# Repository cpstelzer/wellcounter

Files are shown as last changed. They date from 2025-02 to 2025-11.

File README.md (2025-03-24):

# Wellcounter: Automated High-Throughput Phenotyping for Aquatic Microinvertebrates

## Overview
The **Wellcounter** is an open-source platform designed for **automated high-throughput phenotyping** of aquatic microinvertebrates. It enables large-scale ecological experiments by automating **image acquisition, processing, and analysis**, significantly reducing manual effort in tracking population growth and swimming behavior.


**Fig. 1 Wellcounter device**


**Fig. 2 Left: 6-well plate, Middle: Rotifers detected in one well, Right: Detected individuals**

This repository provides resources for **building and using** the Wellcounter, including:
- **Hardware design**: Instructions for assembling the Wellcounter using commercially available and 3D-printed components.
- **Software**: Python-based modules for automated data acquisition, image analysis, and motion tracking.
- **Documentation**: A detailed manual and supplementary materials supporting setup and optimization.

The Wellcounter was introduced in:
> Stelzer, C.-P., & Groffman, D. (2025). Wellcounter: Automated high-throughput phenotyping for aquatic microinvertebrates. Methods in Ecology and Evolution, 00, 1–14. https://doi.org/10.1111/2041-210X.70012

## Features
- **Automated Imaging**: Captures high-resolution images and videos using a motorized **XY linear guide system**.
- **High-Throughput Analysis**: Handles up to **42 six-well plates** (252 populations) per batch. The recording of one batch takes about 1-1.5 hours per day. Multiple batches are possible
- **Image & Motion Analysis**: Quantifies population size and swimming behavior.
- **Customizable & Open-Source**: Fully programmable and adaptable to different microorganisms.
- **3D-Printed Components**: CAD files for custom-designed adapters and mounts included.

## Getting Started
### 1. Hardware Setup
The Wellcounter integrates a **Basler a2A4504-27g5m digital camera**, a **telecentric lens**, and a **darkfield illumination ring**. Detailed **assembly instructions** are available in the **Wellcounter Manual**.

### 2. Software Installation
The Wellcounter software is written in Python and requires installation via **Conda**.
```bash
conda env create -f wellcount6_pi.yml
conda activate wellcount6_pi
```

### 3. Data Acquisition & Analysis
- **Automated Imaging**: The `wc_record_experiment.py` script controls the Wellcounter for video acquisition.
- **Image Analysis**: The `wc_analyze_one_sample.py` script detects and quantifies microorganisms in a recorded movie.
- **Motion Analysis**: The motion module tracks swimming behavior over time.
- **Optimization Module**: Fine-tunes imaging parameters using a training dataset.

## Documentation & Tutorials
- **[Wellcounter Manual](https://github.com/cpstelzer/wellcounter)**: Step-by-step guide to assembling and using the system.
- **Example Datasets**:
  Training & test data available via Zenodo:
  - 10.5281/zenodo.14833208
  - 10.5281/zenodo.14833370
  - 10.5281/zenodo.14833381

## Citation
If you use the Wellcounter in your research, please cite:
> Stelzer, C.-P., & Groffman, D. (2025). Wellcounter: Automated high-throughput phenotyping for aquatic microinvertebrates. Methods in Ecology and Evolution, 00, 1–14. https://doi.org/10.1111/2041-210X.70012

## License
This project is released under an **open-source license**, allowing modifications and contributions from the scientific community.

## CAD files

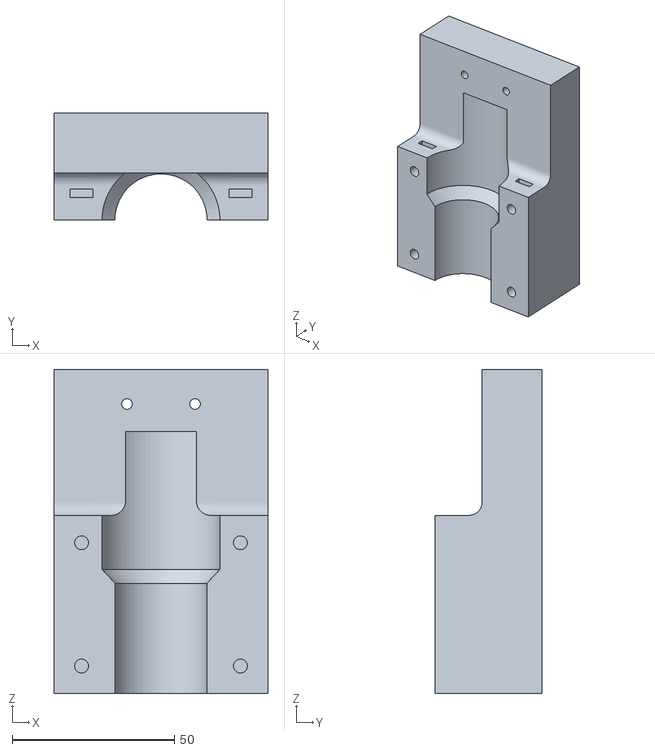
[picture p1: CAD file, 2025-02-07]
3D_print/OPT10M03_adapter_pt2.stl
66.0 x 33.0 x 100.0

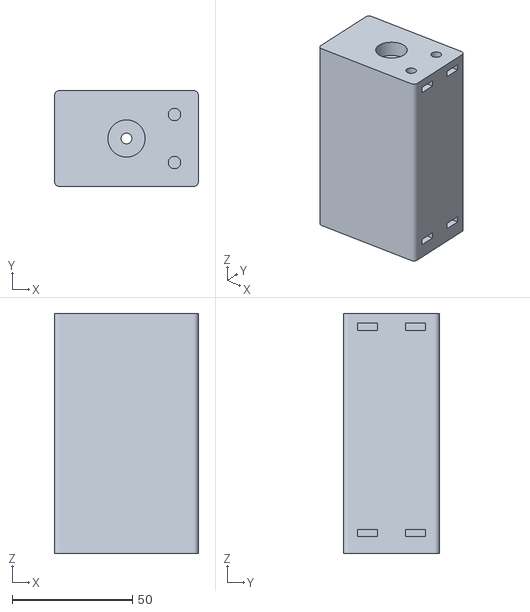
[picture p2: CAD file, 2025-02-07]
3D_print/drag_chain_spacer.stl
60.0 x 40.0 x 100.0

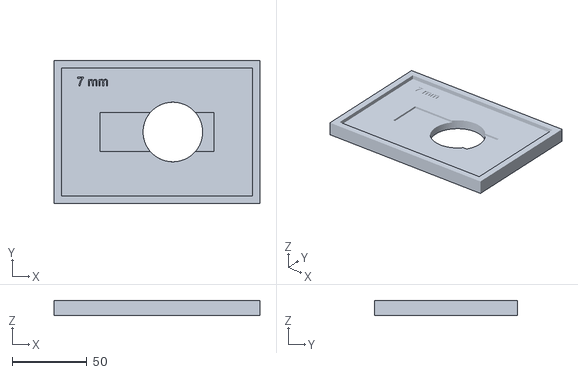
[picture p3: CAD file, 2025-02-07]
3D_print/USAF_1951_slide_holder_7mm.stl
138.3 x 96.0 x 10.0

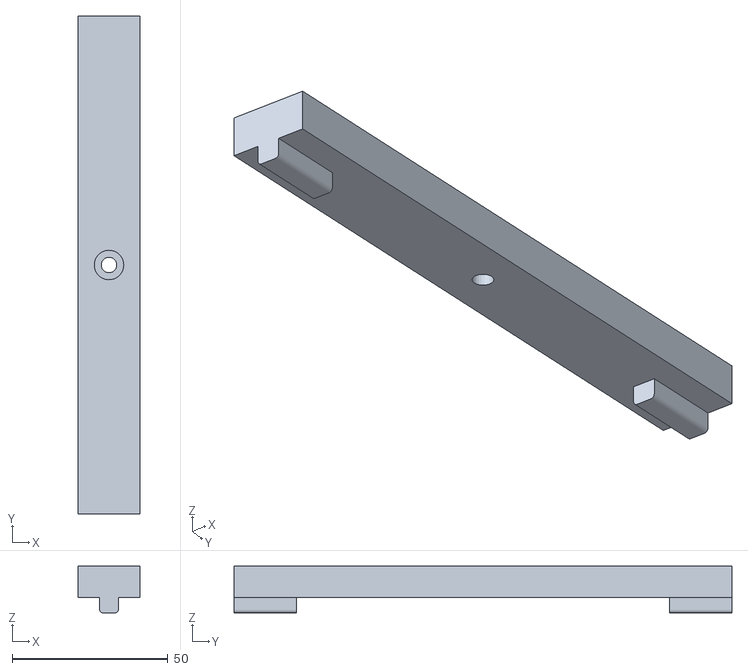
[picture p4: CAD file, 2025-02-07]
3D_print/alignment_rail_long.stl
20.0 x 160.0 x 15.0

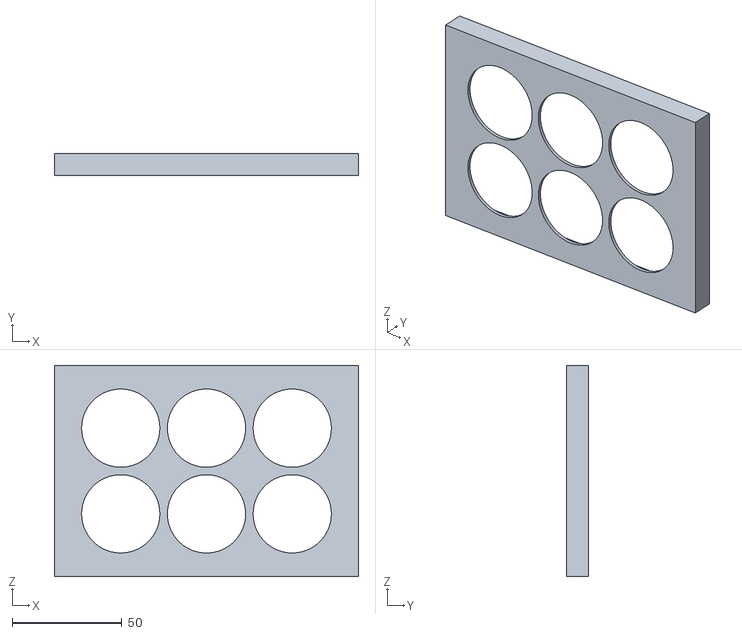
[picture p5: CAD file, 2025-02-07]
3D_print/holder_6wellplate.stl
138.3 x 10.0 x 96.0

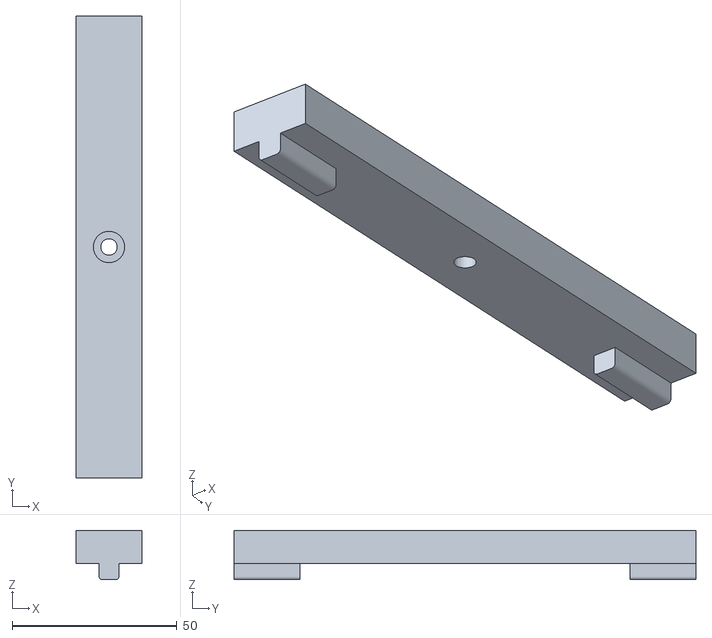
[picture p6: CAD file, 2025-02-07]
3D_print/alignment_rail_short.stl
20.0 x 140.0 x 15.0

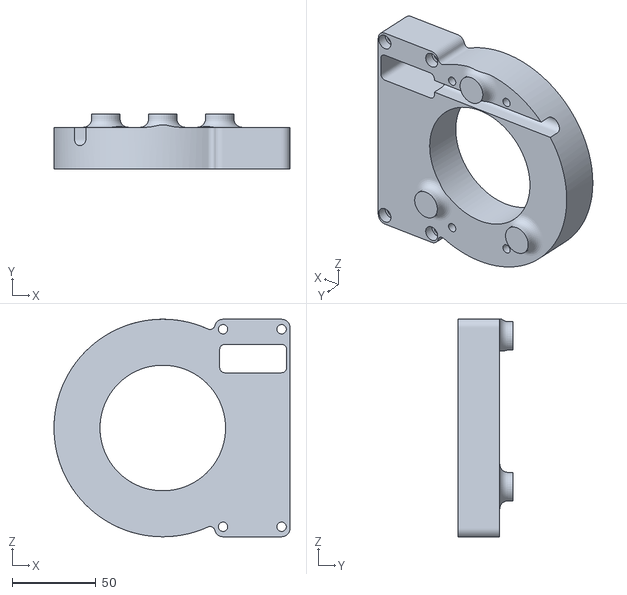
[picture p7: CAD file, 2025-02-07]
3D_print/adapter_ringlight.stl
141.0 x 33.0 x 130.0

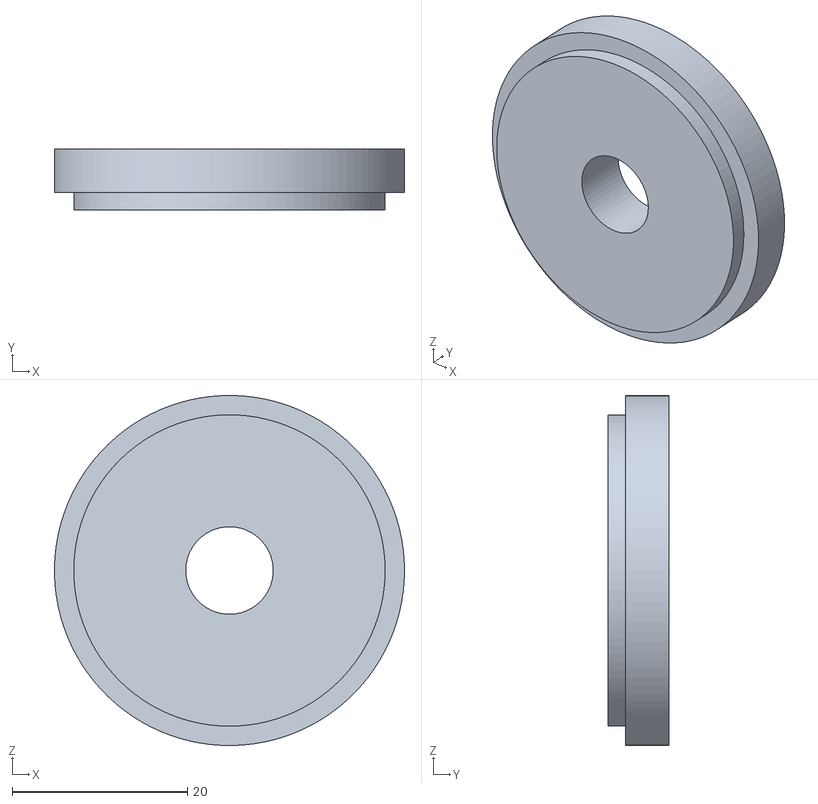
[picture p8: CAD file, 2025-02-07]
3D_print/center_disc_6well_1cm_opening.stl
40.0 x 7.00 x 40.0

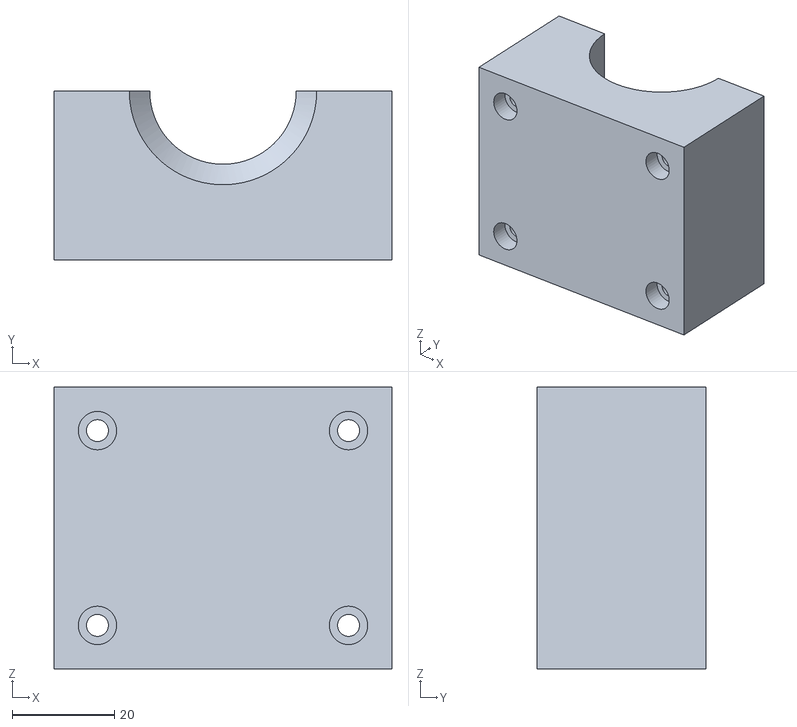
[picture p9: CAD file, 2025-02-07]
3D_print/OPT10M03_adapter_pt1.stl
66.0 x 33.0 x 55.0

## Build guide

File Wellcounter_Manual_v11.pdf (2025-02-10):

# Wellcounter Manual v1.1

### Claus-Peter Stelzer

Research Institute for Limnology, Mondsee, Universität Innsbruck Email: claus-peter.stelzer@uibk.ac.at

This manual is a part of the publication:

Stelzer, C.P. & Groffman, D. (2025) "Wellcounter: Automated High-Throughput Phenotyping for Aquatic Microinvertebrates". Methods in Ecology and Evolution

Future versions of this manual will be available at: https://github.com/cpstelzer/wellcounter

## Table of Contents

## Introduction

The Wellcounter is an advanced platform for automated high-throughput phenotyping of aquatic microinvertebrates (100–2000 µm) using common multiwell plates. It facilitates large-scale ecological experiments by automating image acquisition, processing, and analysis.

The system consists of:

- Hardware: A high-resolution camera, telecentric lens, motorized linear guides, and darkfield illumination.
- Software: Python-based modules for automated data collection and analysis.

This manual provides step-by-step instructions for building the hardware, setting up the software, and using the Wellcounter effectively.

## Building instructions

The Wellcounter device (Fig. 1) integrates an open-source linear guide system, custom 3D-printed parts, and high-quality optical components for capturing well-resolved images of samples. This manual provides detailed instructions on constructing your own Wellcounter device, covering the essential components and assembly steps. By following these guidelines, you should be able to replicate our prototype, or build a device with similar characteristics.

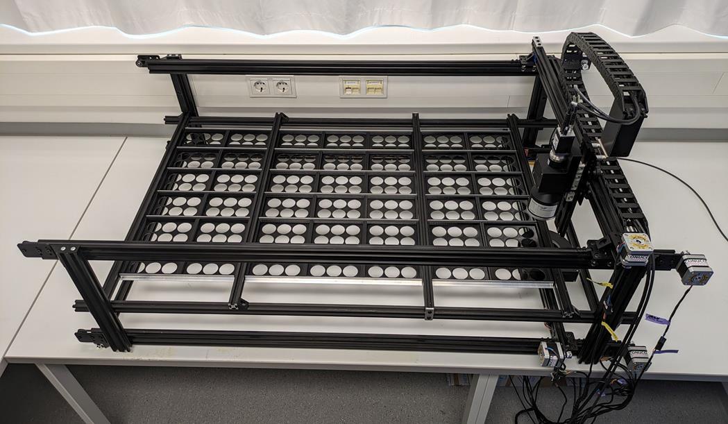
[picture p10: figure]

Fig. 1. The Wellcounter device.

### Linear guide system

We recommend purchasing a pre-assembled linear guide system to save time and avoid potential mechanical issues from DIY construction. The design we use is based on OpenBuilds (https://us.openbuilds.com), an open-source platform that provides affordable and modular components, including aluminum extrusions, belt drives, and stepper motors. You can buy the components or pre-assembled XY linear guides from OpenBuilds (builds.openbuilds.com), or from a reseller (e.g., conucon.de). Usually, such linear guides come at default dimensions, e.g., 1000 x1000 mm, and consist of a frame with two axes travelling in the X- and Y- direction.

In our Wellcounter design, we customized several aspects:

- We use two XY linear guides that are assembled on top of each other. The linear guide at the upper level holds the camera/lens while one at the bottom level holds the ring illumination (Fig. 2).
- The object plane, which holds the six-well plates, is located in between the two linear guides. It is a fixed rectangular frame consisting of 20x20 mm aluminum extrusions and T-profiles (Fig. 2 B-E).
- All three levels are screwed together by four vertical braces consisting of 20x40 mm extrusions. The distance between the top plane and the object plane in our device is 140
mm (Fig. 2 A, E).
- Our linear guides have custom dimensions of 750 x 1150 mm, to better fit on the table in our lab

Checklist for ordering a linear guide system:

- Pre-assembled XY linear guide system
- Stepper motors (NEMA 17 or NEMA 23), motor drivers, and cables
- 12V, 5A power supply
- Microcontroller (e.g., OpenBuilds BlackBox, or Arduino with GRBL firmware)

Apart from these components, you will also need a PC, which is connected via USB to the microcontroller. This PC controls the linear guide either through a low-level table control software provided from the manufacturer (e.g., OpenBuilds CONTROL or CONUCON software), or programmatically via Python commands (e.g., in the Wellcounter acquisition module). For more details, see the next section (Basic software control).

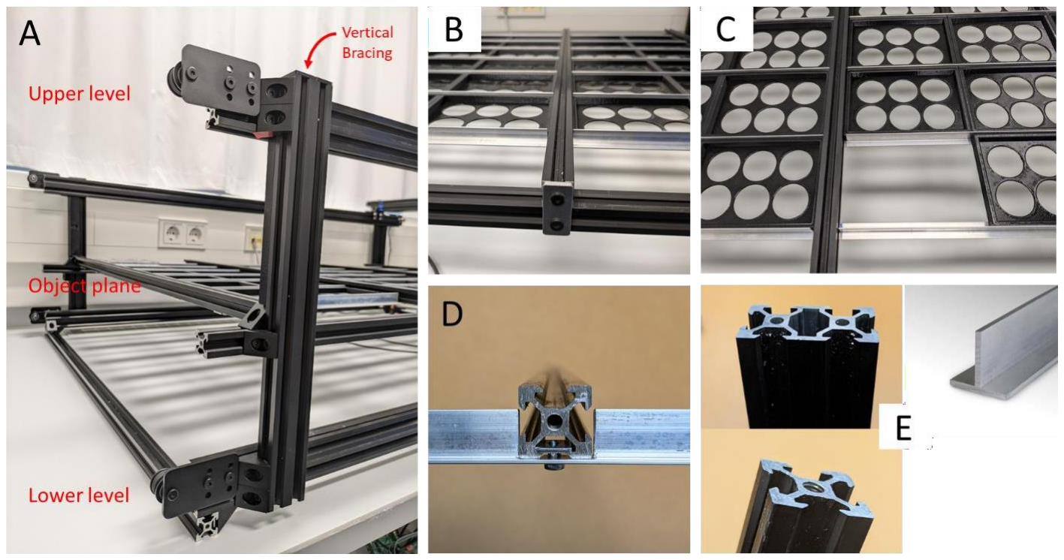
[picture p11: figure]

Fig. 2. Components of the Wellcounter device. A The three levels (Upper level, object plane, lower level) of the Wellcounter device are held together by four vertical braces consisting of 20x40mm aluminum extrusions. B, C The object plane consists of 20x20mm extrusions and aluminum T-profiles, which hold the black 3D-printed wellplate holders. D Connection between T-profiles and 20x20 extrusion. E Raw components of the object plane: 20x40 mm and, 20x20mm extrusions, T-profile.

### Optical components and illumination

The most important aspect of choosing a camera and lens is ensuring that their optical characteristics (e.g., field of view, working distance) align with the spatial constraints of the objects to be imaged, such as the size of a well or the available distance between the camera/lens and the object plane. Ideally, the optical system should be configured so that one well is displayed in a format that fills the camera's sensor. Online calculators (e.g., baslerweb.com/en/tools/lens-selector/) can assist with selecting suitable optical components.

Our Wellcounter prototype utilizes a monochrome digital camera (Basler a2A4504-27g5m) with a Sony IMX541 CMOS sensor, capable of delivering up to 27 frames per second at a resolution of 20.2 MP (4512 x 4512 pixels). We use a telecentric lens (model: OPT-10M035-110) with 0.35X magnification and a working distance of 110 mm. This optical configuration produces a field of view with a 46.3 mm diameter, precisely covering one well of a 6-well plate (Greiner Bio One, Model: 657160). The camera is connected to a PC through a 5-GigE interface card. Darkfield background illumination is provided by an MBJ horizontal ringlight HDF-07-BE-s (MBJ imaging, Hamburg, Germany) with a peak wavelength of 465 nm (blue light).

To aid in selecting components for similar applications, we offer the following recommendations:

- Use an industrial-grade camera that can be controlled via Python commands (e.g., through Basler Pylon). Consumer digital cameras are generally unsuitable, as they lack low-level control capabilities and store images/movies on the camera itself rather than on a computer, where the analysis is performed.
- If color is not essential to your application, opt for a monochrome camera because it provides higher sensitivity and greater resolution by capturing more light at each pixel compared to a color sensor. Monochrome cameras avoid the color filter array used in color sensors, allowing for sharper imaging, especially beneficial in low-light conditions or when using specific wavelengths for illumination.
- Invest in a telecentric lens. Although telecentric lenses are considerably more expensive than standard lenses, they produce an essentially distortion-free image, ensuring accurate representation of each object's position and size.
- Ensure that no downstream component limits the camera's frame rate. Use a suitable high-bandwidth interface card for the computer if needed. For example, we added a 5-GigE interface card to our setup.
- Monochrome illumination, ideally atshort wavelengths, offers superior sharpness. We use blue light illumination at 465 nm, but other wavelengths can also be effective.

### 3D-printed components

In the Wellcounter, we use 3D-printed adapters to mount the camera/lens and ring light onto the linear guides, or as holders for 6-well plates onto the object plane (Fig. 3). We used black PETG as printing material, which is cost-efficient, easy to print, and durable.

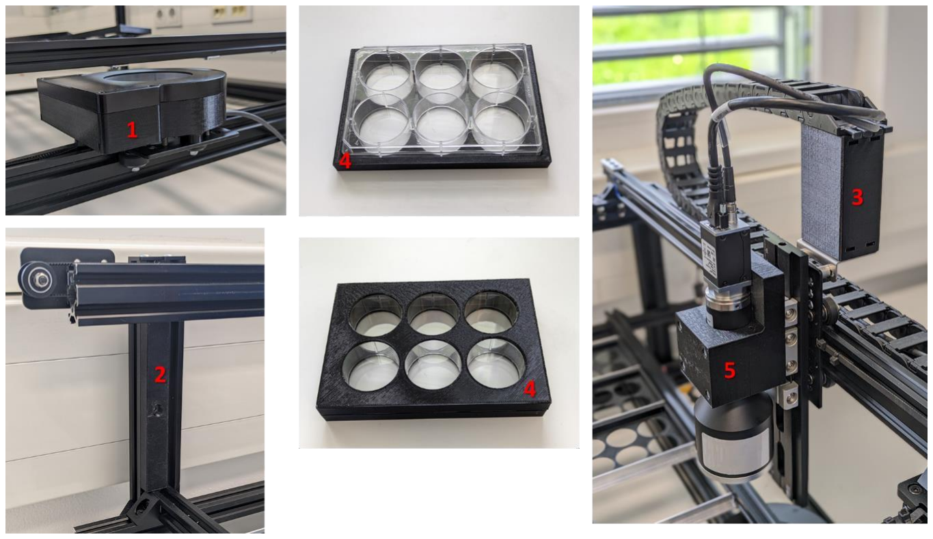
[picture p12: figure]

Fig. 3. 3D-printed parts of the Wellcounter. 1 Mounting adapter for ring illumination, 2 Alignment rail for adjusting the distance between upper level and object plane, 3 Spacer for drag chain, 4 Well plate holder used to mount well plates onto the object plane, or can be placed on top of a well plate to block light signals outside the well, 5 Mounting adapter for camera and lens.

If you do not have access to a 3D-printer, you can upload the provided STL-files to a 3D printing service. However, if you chose this approach, we recommend having a test print done for one of the 6-well plate holders before printing the full set of 84 pieces, since the tolerances of 3D printed parts may vary from printer to printer.

The 3D printed parts are specifically designed for the optical components stated above. They will probably not fit for different models, or if manufacturers chose to change the dimensions of the existing models. In these cases, it would be necessary to design new adapters that match the dimensions of the new optical components.

## Basic software control

The goal of this section is to familiarize you with software control of the Wellcounter device. We will install the Conda environment, which contains all the dependencies for running the Wellcounter software written in Python. We will also generate a csv fie in which the coordinates to the physical positions of all plates and wells on the object plane are stored.

### Background

At the low level, the XY linear guide system of the Wellcounter is controlled by commands written in G-code, which tell the motors how to move. This G-code is sent to the microcontroller, which converts it into electrical signals that ultimately drive the stepper motors translate it into actions like moving along the X and Y axes.

Example of a G-code command:

G1 X5 Y10

This moves the device 5 units in the X-axis and 10 units in the Y-axis. Your linear guide system should come with a software that allows directly entering G-code commands.

G-code commands can also be sent to the microcontroller from within a Python-program using the package pyserial, which is the method how the Wellcounter interfaces with the linear guide. Here is the same command send from within Python:

gcode_command = 'G1 X5 Y10\n'

ser.write(gcode_command.encode('utf-8'))

Note that ‘\n’ (newline) indicates the end of the command.

### Setting up the Conda environment

To run the Wellcounter software on your local computer, you need to first replicate the required environment with all its dependencies. The easiest way to accomplish this is to install the package manager Anaconda on your computer (http://anaconda.org/). After installing Anaconda, complete the following steps:

1) Copy the Wellcounter environment-file to a destination folder on your PC, e.g.:

C:/Users/Anaconda/wellcount6_pi.yml
2) Install the environment on your PC with the following command:

conda env create -f C:/Users/Anaconda/wellcount6_pi.yml
This step only needs to be done once.
3) After the environment has been installed, open the Anaconda terminal and activate the

Wellcounter environment by typing:

conda activate wellcount6_pi
The terminalshould now display “(wellcount6_pi)” followed by your current working directory.
4) Copy all the Wellcounter software files into your working directory. This step only needs to be

done once.

You can verify the correct installation of your Wellcounter Conda-environment by running an analysis of pre-recorded sample movies. To run one of the example scripts, e.g., wc_analyze_one_sample.py, follow these steps:

- Copy the mp4-movie file that is to be analyzed into any directory of your choice.

- Open the example script wc_analyze_one_sample.py in an editor of your choice (e.g.,

Spyder, which is part of the Anaconda package) and adjust the variables ‘data_dir’ and

‘video_file’ to match the location of your video-file. Save these changes.

- To execute the script, go to the Anaconda terminal (‘wellcount6_pi’ activated), navigate

to the directory where your Wellcounter software is stored, and and type:

python wc_analyze_one_sample.py
- Depending on the hardware of your computer, the analysis will take 20-60 seconds (if

only counting is done), or a few minutes (if motion analysis is done as well) and it will

output the main results on the screen (Fig. 4)

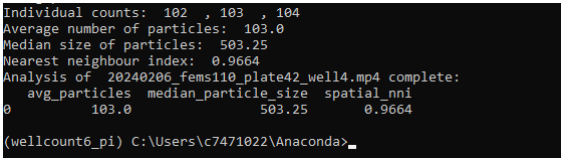
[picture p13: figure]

Fig. 4. Typical screen output after running image analysis.

Furthermore, after the analysis is complete, you will find two new folders in the same directory as

your mp4-file, which contain the results of particle detection and motion analysis, respectively (Fig.

5).

Fig. 5 Folders containing the results of image and motion analysis.

### Generating the wellpositions_all.csv file

During recording of an experiment, the Wellcounter moves the camera/illumination unit to each individual well in the object plane, thus visiting a total of up to 42 x 6 = 252 wells. The G-code commands required for this movement are calculated based on the positions of each of these 252 wells in the object plane. Before the first use of the Wellcounter, the exact positions of these wells have to be empirically determined and stored in a file called wellpositions_all.csv. This procedure needs to be done only once, unless you make changes in the object plane that alter the physical arrangement of the well plates. As a reference point (X0, Y0) of the coordinate system of the object plane, we use the center of “well 6” of “plate 42”, which is located in the low right corner of the object plane (Fig. 7). The workflow for generating the wellpositions_all.csv file is as follows:

- Put a small piece of white cardboard behind the ring illumination, to create a white background (see below, Initial calibration in Workflow1: Data Acquisition). Place all 42 wellplate holders on the object plane.
- Start your low-level table control software provided with the XY linear guide (e.g., CONUCON software) and the camera control software of your camera manufacturer (e.g., Basler Pylon).
- Move the camera and illumination units to “well 6” of “plate 42”. Tare this position to the coordinates 0, 0 (X, Y). This procedure is described in more detail below (see below, Initial calibration in Workflow1: Data Acquisition).
- Now move the camera and illumination to “well 6” of “plate 41”. Note the XY-coordinates of well 6 of plate 41 and continue with each the remaining 40 plate holders.
- Enter all 42 coordinates in a text editor and save the results as a csv-file (wellpositions_w6.csv), which will look like this
plate,well,originX,originY
1,6,86.680,48.448
2,6,86.714,38.704
3,6,86.740,28.986
4,6,86.775,19.256
…
- To calculate the positions of the remaining wells no. 1-5 of each plate, you can use our Python script calculate_all_wellpositions.py. This script outputs the file wellpositions_all.csv which contains the coordinates of all 42x6=252 wells:
plate,well,X,Y
1,1,94.48,52.35
1,2,90.58,52.35
1,3,86.68,52.35
1,4,94.48,48.45
1,5,90.58,48.45
1,6,86.68,48.45
2,1,94.51,42.6
…

## Using the Wellcounter

Before you start using the Wellcounter, make sure you have all the hardware set up, all hardware drivers installed (e.g., linear guide, camera), and the ‘wellcount6_pi’ Conda-environment installed and activated. In the following, we describe three workflows, data acquisition, image and motion analysis, and optimize imaging parameters.

### Workflow1: Data Acquisition

This workflow guides you through capturing experimental data using the Wellcounter acquisition module. The purpose of the acquisition module is to automate the recording of experimental data by controlling hardware components to capture images and videos of samples in multiwell plates. The Wellcounter can be loaded with up to 42 six-well plates (6 rows x 7 columns, Fig. 6). The camera/light-unit can travel to each well and take photos or record movies.

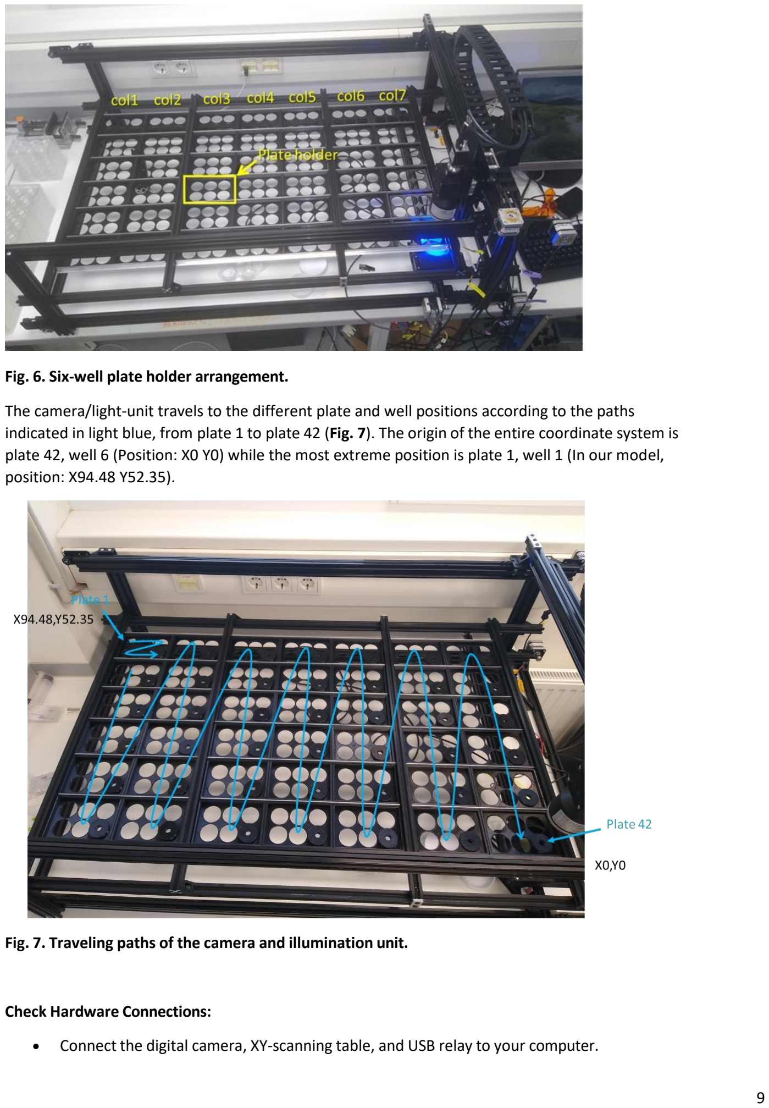
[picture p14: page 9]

Fig. 6. Six-well plate holder arrangement.

The camera/light-unit travels to the different plate and well positions according to the paths indicated in light blue, from plate 1 to plate 42 (Fig. 7). The origin of the entire coordinate system is plate 42, well 6 (Position: X0 Y0) while the most extreme position is plate 1, well 1 (In our model, position: X94.48 Y52.35).

Fig. 7. Traveling paths of the camera and illumination unit.

Check Hardware Connections:

- Connect the digital camera, XY-scanning table, and USB relay to your computer.

- Verify the serial ports used by the devices and update the script accordingly (e.g., ser.port = 'COM5' for the XY-table, portName = 'COM4' for the USB relay).

Configure Paths and Parameters:

- Open wc_record_experiment.py in an editor.
- Set the output_folder and movies_folder variables in the script to specify where images and videos will be saved.
- Adjust movement parameters such as speed and acceleration if needed.
- Ensure the csv_file variable points to the correct CSV file containing well positions.

Prepare the wellpositions CSV file:

- Create or verify the CSV file (e.g., wellpositions_all.csv) containing the X and Y coordinates of each well. See above, Generating the wellpositions_all.csv file.
- The CSV should have columns like plate, well, originX, originY.

Initial calibration

Before each run, a calibration of the XY linear guide isrecommended. In this procedure, you assign the coordinates X0, Y0 to the 6

th well of the 42nd plate (see Fig. 5). Below, we describe our protocol using the CONUCON software and Basler Pylon software (for low-level table and camera control, respectively):

1. By default, the background of the ring illumination is black (Fig. 8: 1). Place a white piece of paper behind the background illumination to create a white background (2). Put back the plate holder (3).

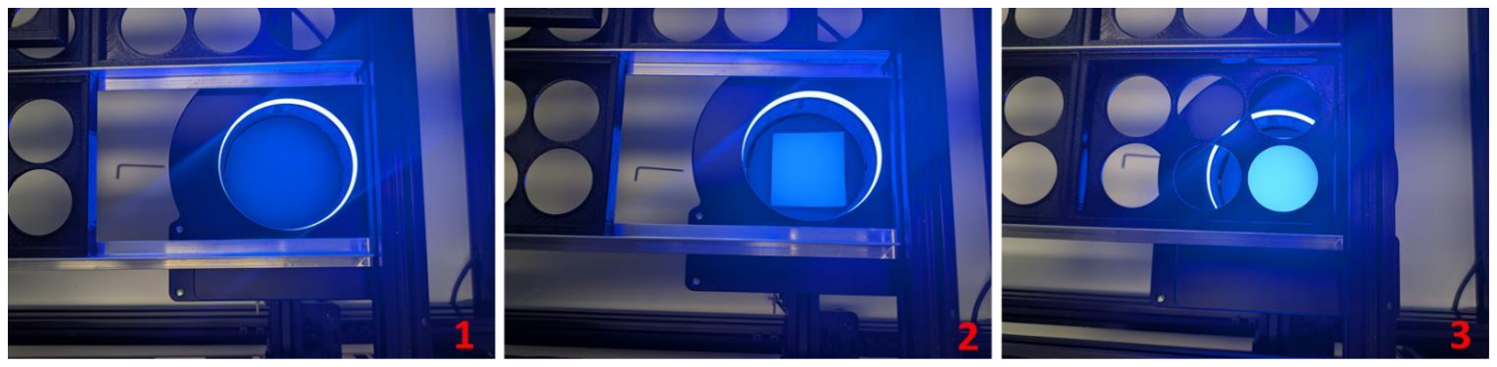
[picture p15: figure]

Fig. 8. Creating a white background for calibration of wellpositions.

2. Pylon Viewer: Select the camera (Fig. 9: 1), switch it on (2), and turn on “live view” (3). Check the image: You should see a white circle that is perfectly centered. If this is not the case, you have to align the camera as outlined in the next step with the CONUCON software.

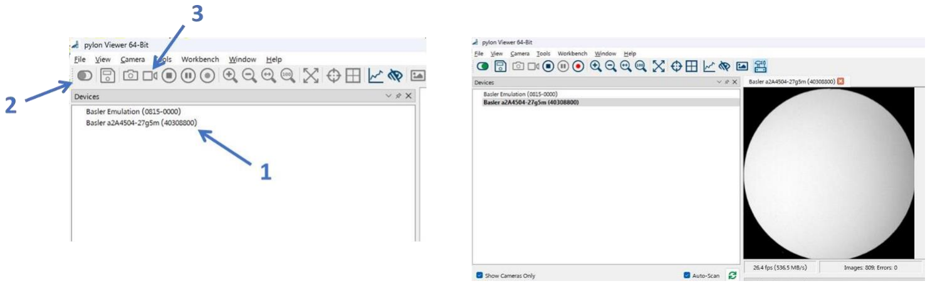
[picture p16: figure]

Fig. 9. Calibration procedure: Establishing connection to camera.

3. CONUCON software: Press “Connect” (Fig. 1) and then press “Unlock” (2). The two Buttons should then light on as green and display “Disconnect” and “Start”, respectively. To align the camera, enter updated X or Y positions into the command line of the CONUCON software.

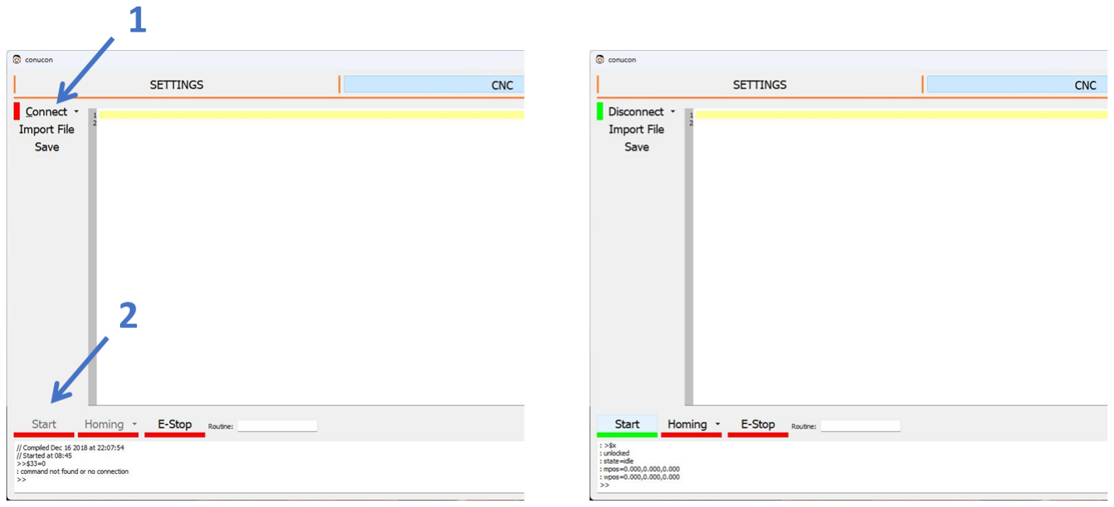
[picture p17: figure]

Fig. 10. Calibration procedure: Establishing connection to XY linear guide.

4. Enter the values as numbers preceded by X or Y, e.g.: X-0.05. When you press return, the table should move. The values you enter here are positions, not movements! Make sure you only enter small values for the refined position (e.g., 0.05 – 0.1).

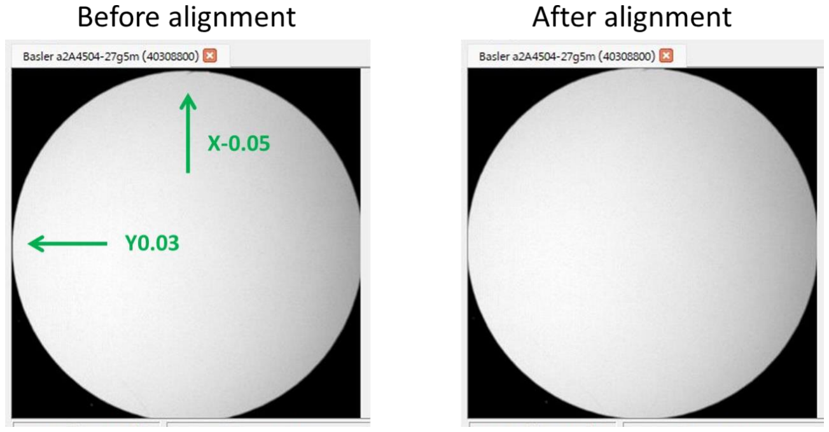
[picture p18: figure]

Fig. 11. Centering the reference well at X0 Y0.

5. Once the white circle is perfectly centered (Fig. 11), press “Disconnect” and close the CONUCON program. This effectively tares the current position to X0 Y0. Then, switch off the camera and close the Pylon Viewer program. It is essential to end both programs, otherwise it will cause conflicts with the measurement program.
6. Remove the white cardboard piece from the ring lamp and place back plate holder 42.
7. The Wellcounter is now ready for image acquisition!

Prepare the Experiment:

- Place all your six-well plates with the microorganisms (in 5ml culture medium) on the XY-scanning table according to your experimental design.
- If you want to make full use of the Wellcounter’s high throughput capabilities you should prepare an Excel file containing information about which treatment is linked to which batch/well/plate, from which you export a treatments.csv file (Fig. 12). You can use this treatments.csv file later for automatically analyzing an entire experiment with thousands of recorded movies.

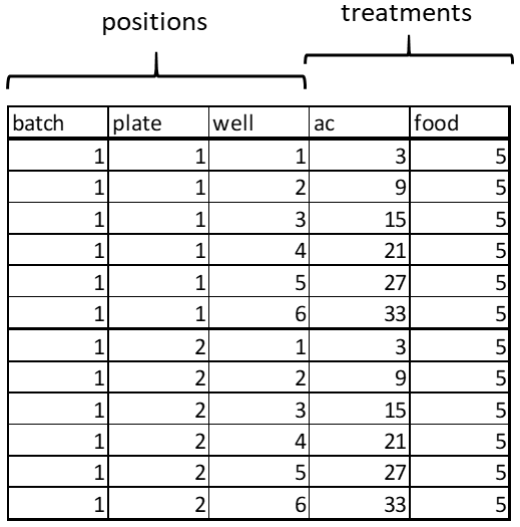
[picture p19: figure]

Fig. 12. Example ofstoring experimental information in the treatments.csv file.

- Remove lids and place a lid covers (Fig. 13) on each plate, and ensure the room is darkened.

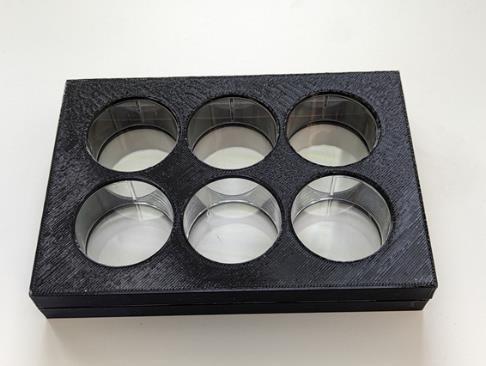
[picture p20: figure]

Fig. 13. Wellplate with lid cover on the top.

Run the script:

- Activate the Wellcounter Conda-environment
- Execute wc_record_experiment.py in your Python environment.
- When prompted (Fig. 14), enter the batch number (an integer representing your experiment batch).
- Check and confirm that allsetup conditions are met by pressing Enter.

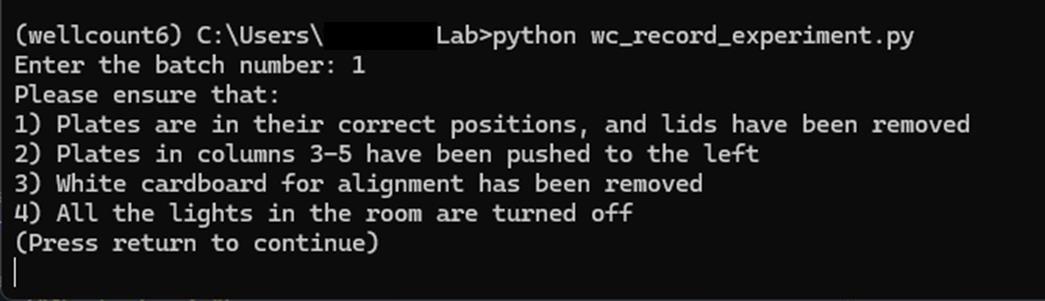
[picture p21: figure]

Fig. 14. Initial dialog when running wc_record_experiment.py

Upon running the script, the Wellcounter will move the XY-scanning table to each well position, control the lighting by turning the relay on and off, record videos at each well position, log video recording times and positions.

The output consists of:

- Videos of each well saved in the specified movies_folder. The naming of the video files follows a strict pattern of date, batch number, plate number, and well number, which facilitates automated analysis later on.

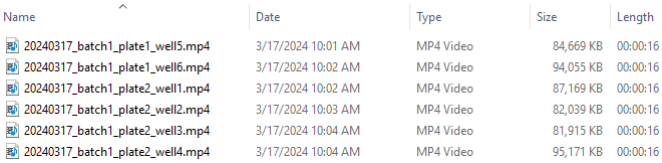
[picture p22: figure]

Fig. 15. Example of movie files recorded with the Wellcounter.

- A log file (video_log.csv) of the entire experiment, containing additional information, such as frame rate, total frames recorded of positions and recording duration of each recorded movie.

### Workflow 2: Image and motion analysis

In the following, we process recorded videos using the imaging and motion module. Here, we assume that you have already fine-tuned the detection parameters for your focal animals. If you use an organism of similar size or larger than Brachionus plicatilis (~200-400μm in length), the default parameters should work. If not, consider the following section (Workflow 3: Optimize detection parameters). If you just want to test whether the Wellcounter software runs on your computer, feel free to use one of our pre-recorded mp4-movies provided as supplementary data with the publication.

Configure Imaging Parameters:

- Open the wellcounter_config.yml file using a code editor of your choice (e.g., MS Visual Studio).
- Check and/or adjust parameters under particle_detection:
- microorganism_threshold: Pixel intensity threshold for detecting particles(e.g., 24).
- min_microorganism_area: Minimum area in pixels for detected particles (e.g., 210).
- Set output options to specify which outputs to generate (e.g., particle_detection: True to save labeled images).

Process Videos:

- Open an Anaconda terminal, activate your Wellcounter environment (conda activate, and navigate to the folder where your Wellcounter software (modules, scripts) is stored.
- For analyzing one sample, you can use the script wc_analyze_one_sample.py. In this case, you need to provide within the script:
- The path to the directory of your video file (variable: data_dir).
- The name of your video file (variable: video_file).
- Open the script in a code editor of your choice (e.g., MS Visual Studio), edit these data, and save.
- Start the analysis by entering python wc_analyze_one_sample.py in the Anaconda terminal.
- For analyzing an entire experiment consisting of thousands of videos, you can use the script wc_analyze_experiment.py. In this case, you need to provide within the script:
- The path to your video files (variable: data_dir)
- The treatments.csv file with information about which treatment is linked to which batch/well/plate (variable: treat_file)
- A name for the csv-file where the results are stored (variable: outfile)
- The start and end date of your experiment as a number in the format ‘yyyymmdd’ (variables: start_date and end_date)
- Open the script in a code editor of your choice (e.g., MS Visual Studio), edit these data, and save.
- Start the analysis by entering python wc_analyze_experiment.py in the Anaconda terminal.
- The script then iterates through each sample for each day of the experiment, performs analyses on the populations (including counting and motion analysis), and combines the results with the information on the treatments, which are saved in a csv-file specified by the variable outfile.

### Workflow 3: Optimize detection parameters

To ensure that the Wellcounter reliably and exclusively detects your study organism, it is necessary to specify suitable values for the imaging parameters microorganism_treshold and min_microorganism_area in wellcounter_config.yml. There are two approaches to do this, (1) by interactively testing a few parameter combinations and (2) using a grid search to examine a wide parameter space and find the best parameter combination.

Interactive approach
In this approach you are changing the parameters manually and then examine their results after running the imaging module:
- Open wellcounter_config.yml in a code editor of your choice (e.g., MS Visual Studio).
- Adjust the parameters under particle_detection:
- microorganism_threshold: Pixel intensity threshold for detecting particles(e.g., 24).
- min_microorganism_area: Minimum area in pixels for detected particles (e.g., 210).
- Set outputs options to generate labelled output images (e.g., particle_detection: True to save labeled images).
- Save and close wellcounter_config.yml
- Run the script wc_analyze_one_sample.py on a video of your choice (see Process Videos)
- Examine the labelled output images. If many animals were missed, you may want to decrease the values of microorganism_threshold and/or min_microorganism_area. If there are many false positives, you should increase the values of microorganism_threshold and/or min_microorganism_area in the next iteration.

This approach should lead to a reasonably good detection rate after a few iterations. However, it is unlikely to find the optimal parameter combination.

Grid search
A more comprehensive, but also more time-consuming approach to determine the optimal imaging parameter combinations.

Overview of Steps (see Fig. 16)

1) Running the imaging module on multiple movies with the default parameters (or parameters determined by the interactive approach)
2) Manually classifying false positives using the review module
3) Manually classifying false negatives using an image editor (e.g., Irfanview)
4) Compiling a ‘ground truth’ dataset for all movies (by removing false positives and adding false negatives to the particle data for each movie)
5) Running the optimization module to find the best imaging parameter combination

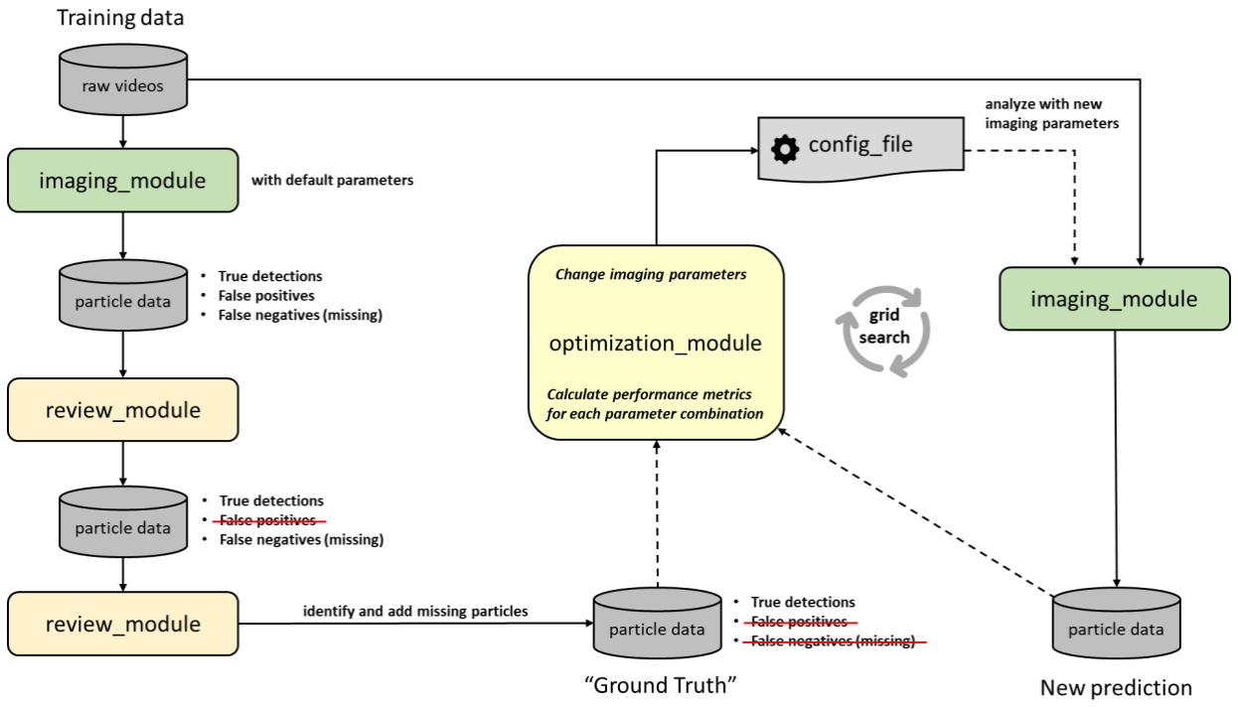
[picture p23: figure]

Fig. 16. Schematic of grid search to determine optimal imaging parameters for a new model organism.

This workflow focuses on improving detection accuracy by manually reviewing detected particles and optimizing imaging parameters. It is used when adapting the Wellcounter to a new study organism for the first time, or if major changes in the optical system have been done (e.g., installing a new camera).

Prerequisites

- A set of videos for generating labeled training data.
- The default setting of the imaging parameters microorganism_treshold and min_microorganism_area should already detect some of your study organisms. You can check this by running wc_analyze_one_samlpe.py on one of your videos and examining the results. If detection rate is very low, or if false positive detections are very high, you should first use the Interactive approach(see above) for finding better initial values for the imaging parameters
1) Run the imaging module with default/initial parameters
- Check if your wellcounter_config.yml file contains the desired default values for microorganism_treshold and min_microorganism_area
- Comment out the line “motion_df = wmm.perform_motion_analysis(video_path)” in wc_analyze_one_sample.py by entering a # in the beginning of this line. This willsuppress motion analysis, which is not useful at the moment.

- Run the image analysis for each movie. This will generate a results folder containing the name of your movie with “_particle_detection” added, as well as a file called table_of_particles.csv.
2) Manually classifying false positives using the review module
- Use the provided script wc_assign_particletypes.py. Before running the script, open it in an editor and read the description on how to use it.
- Assign categories (e.g., true_swimming, true_stationary, false positive) to each particle (Fig. 17).

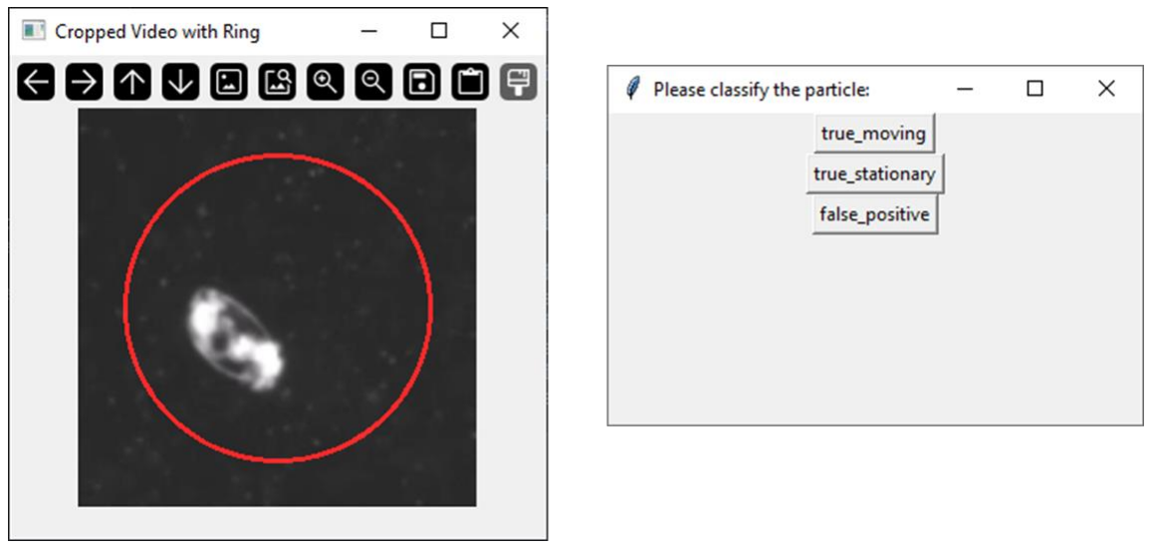
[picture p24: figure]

Fig. 17. Example screenshot of wc_assign_particletypes.py (review module).

- Tip: You don’t need to watch each movie of each particle to the end. Once you recognize the category, press “q” to skip the rest of the movie and enter the category.
- Output: Running this part of the script will edit your table_of_particles.csv by adding a new column containing your assigned categories, which will be saved as table_of_particles_fp.csv in the same folder.
3) Manually classifying false negatives using the review module
- After all particles have been assigned the categories ‘true’ or ‘false positive’, the script wc_assign_particletypes.py will directly continue with the detection of false negatives (i.e., animals that are visible in the first frame, but were not detected by the initial parameter settings).
- To assist in detecting false negatives, the script wc_assign_particletypes.py splits the first frame of the movie into four quadrants, for better visibility. For each quadrant (Fig. 18), it displays the annotated image of the first frame (with true positives marked in green and false positives in red) and then repeatedly plays selected frames from later in the video
(25. 50, 75% of the video, and the last frame) to help you in spotting false negatives. For each quadrant, there are two phases. In the ‘display phase’, the program displays the current quadrant and quickly iterates through the different frames of the movie. Once you press “q”, you will enter the ‘marking phase’, where only the first frame is displayed. To record the positions of false negatives, click on all false negative particles that you have identified previously during the animation phase. After all false negatives have been marked, press ‘Space’ to continue to the next quadrant.

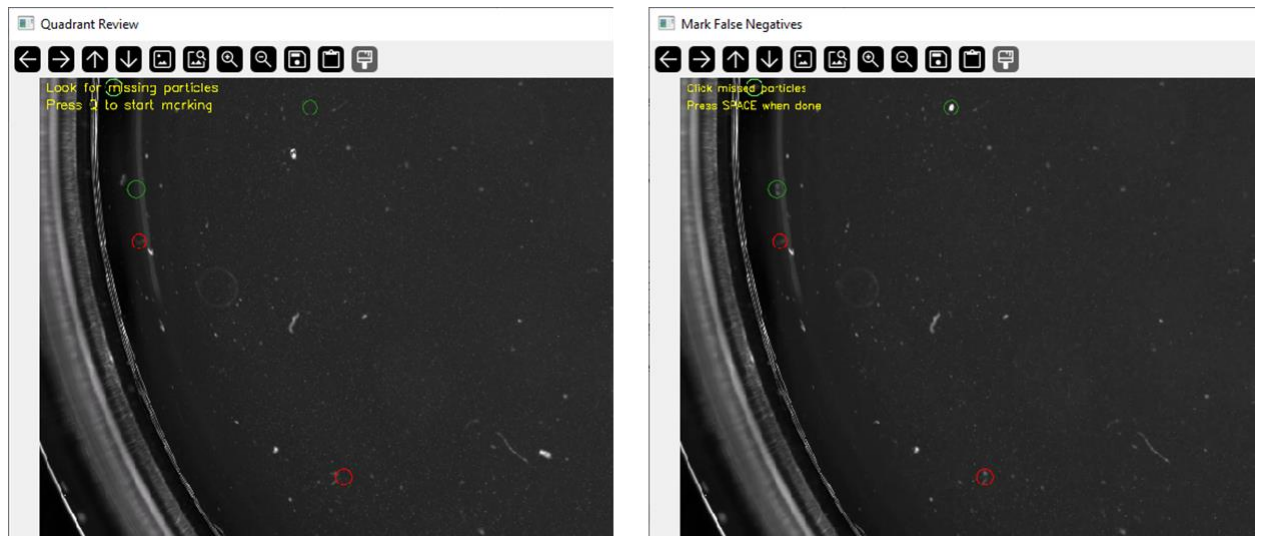
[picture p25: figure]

Fig. 18. Example screenshot of wc_assign_particletypes.py (review module) during detection of false negatives. Left: Animation phase. Right: Marking phase. Note that this image does not display the full quadrant.

- After all the four quadrants have been processed, the program will update the table_of_particles variable by adding the coordinates of the false negatives and their particle categorie (value: 4) and save it as table_of_particles_cat.csv. You will also find a new image (first_frame_typelabels.jpg, Fig. 19) containing all particles labelled in different colors according to their assigned category (true, false positive, false negative).

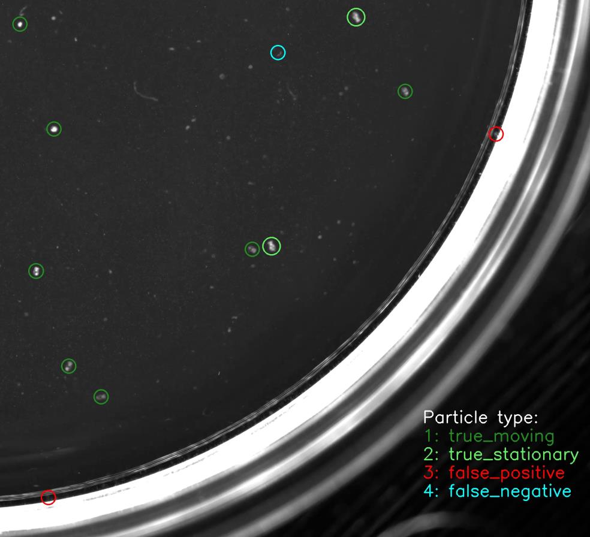
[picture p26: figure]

Fig. 19. Example image with the different categories of particle types. Note that this image does not display the full quadrant.

4) Update your final_particles file file in a text editor
- Remove all false positive detections (i.e., lines with particle category = 3) and rename/save this final table to “all_females.csv”
5) Running the optimization module
- To run the optimization module, you need
- The raw movies
- The all_females.csv files corresponding to each raw movie, which contain the ‘ground truth’ information (i.e., the coordinates of all particles that can be detected)
- A copy of your wellcounter_config.yml file (Store the original version at a safe place, as the optimization module will alter the config file)
- Edit the optimization parameters in your wellcounter_config.yml file under the section “optimize”:
- The start value, end value, and step size of each optimization parameter
- Paths to training data and a directory for the output of optimization (optimize_imaging_parameters_<date>.csv)
- Save the configuration file
- Run the optimization module with the command python
wellcounter_optimization_module.py. During analysis, the screen output
will display the current parameter settings and their associated performance metrics (Fig. 20). All these data will also be saved in the file optimize_imaging_parameters_<date>.csv.

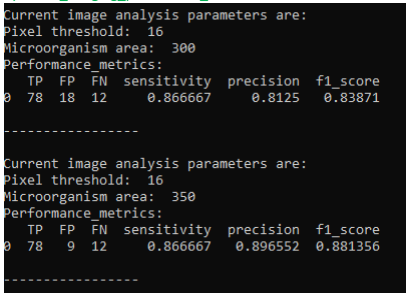
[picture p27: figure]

Fig. 20. Screen output of the optimization module.

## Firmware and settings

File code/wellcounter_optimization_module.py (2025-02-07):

# -*- coding: utf-8 -*-
"""
Wellcounter optimization module

This software is part of the following publication:
"Wellcounter: Automated High-Throughput Phenotyping for Aquatic Microinvertebrates"
Methods in Ecology and Evolution

The latest version can be found at https://github.com/cpstelzer/wellcounter


Description:
This module is designed to automate the optimization of imaging parameters 
for detecting microorganisms recorded with the WELLCOUNTER. 

The module includes functions for reading and writing the WELLCOUNTER 
configuration file, backing up and restoring configurations, calculating 
performance metrics, and performing batch optimization of imaging parameters. 

Note: Optimization parameters, e.g., the path to the training data, have to be 
set in the WELLCOUNTER configuration file (wellcounter_config.yml)

Note: Portions of the code in this file were generated using ChatGPT v4.0.
      All AI-generated content has been rigorously validated and tested by the 
      authors. The corresponding author accepts full responsibility for the 
      AI-assisted portions of the code.

Author: Claus-Peter Stelzer
Date: 2025-02-07

"""

import pandas as pd
import os
import numpy as np
import yaml
import tempfile
import shutil
import wellcounter_imaging_module as wim
import logging
from datetime import date   

# Get the current date
current_date = date.today().strftime("%Y%m%d")

# Set up logging
logging.basicConfig(filename=f'optimize_imaging_parameters_{current_date}_logfile.log', level=logging.INFO, format='%(asctime)s:%(levelname)s:%(message)s')

def read_config(config_path="wellcounter_config.yml"):
    """
    Function to read the config file.
    """
    try:
        with open(config_path, "r") as config_file:
            config = yaml.load(config_file, Loader=yaml.FullLoader)
        return config
    except Exception as e:
        logging.error(f"Error reading config file: {e}")
        raise

def write_config(config, config_path="wellcounter_config.yml"):
    """
    Function to write the config file.
    """
    try:
        with open(config_path, "w") as config_file:
            yaml.dump(config, config_file)
    except Exception as e:
        logging.error(f"Error writing config file: {e}")
        raise

def backup_config(config_path="wellcounter_config.yml"):
    try:
        config = read_config(config_path)
        # Open the temporary file in text mode
        with tempfile.NamedTemporaryFile(mode='w+', delete=False) as temp_file:
            yaml.dump(config, temp_file)
        return temp_file.name
    except Exception as e:
        logging.error(f"Error backing up config: {e}")
        raise


def restore_config(backup_file, config_path="wellcounter_config.yml"):
    try:
        shutil.copy(backup_file, config_path)
        os.remove(backup_file)
    except Exception as e:
        logging.error(f"Error restoring config: {e}")
        raise
        
   

def calculate_performance_metrics(df):
    """
    Calculate various performance metrics of particle detection in an image sample.
    
    Note: These calculations do not include true negatives and all derived measures 
    (e.g., accuracy) since true negatives are not relevant to the used dataset (WELLCOUNTER).

    Parameters
    ----------
    df : pandas.DataFrame
        DataFrame containing all particles in a sample, detected by a certain method (query) 
        compared to the actual particles (reference). Must contain 'in_ref', 'in_query', 
        and 'particle_type' columns with Boolean values indicating particle detection status.

    Returns
    -------
    pandas.DataFrame
        DataFrame containing performance metrics like confusion matrix (excluding TN), sensitivity, etc.
    """
    
    if not {'in_ref', 'in_query'}.issubset(df.columns):
        raise ValueError("DataFrame must contain 'in_ref', 'in_query' columns")

    
    # Calculate confusion matrix elements, excluding true negatives
    true_positives = np.sum((df['in_ref']) & (df['in_query']))
    false_positives = np.sum(~df['in_ref'] & df['in_query'])
    false_negatives = np.sum(df['in_ref'] & ~df['in_query'])

    # Handle cases with zero denominators
    sensitivity = true_positives / (true_positives + false_negatives) if (true_positives + false_negatives) > 0 else 0
    precision = true_positives / (true_positives + false_positives) if (true_positives + false_positives) > 0 else 0
    f1_score = 2 * (precision * sensitivity) / (precision + sensitivity) if (precision + sensitivity) > 0 else 0

    # Create a DataFrame for metrics, excluding TN, specificity, and npv
    df_metrics = pd.DataFrame({
        'TP': [true_positives],
        'FP': [false_positives],
        'FN': [false_negatives],
        'sensitivity': [sensitivity],
        'precision': [precision],
        'f1_score': [f1_score]
    })

    print("Performance_metrics:")
    print(df_metrics)
    print("")
    print("-----------------")
    print("")

    return df_metrics


def evaluate_imaging_parameters_OLD(training_path='E:/'):
    """
    Assess the effects of two imaging parameters (microorganism_threshold, min_microorganism_area) on 
    female detection performance metrics. Iterates through a curated training dataset.

    Parameters
    ----------
    microorganism_threshold: int
        Intensity threshold value of pixel (range: 0-255; default: 30)
    min_microorganism_area: int
        Contour area of detected particle (default: 150 pixels)
    training_path: str
        Main path to the dataset
    config_path: str
        Path to the configuration file

    Returns
    -------
    DataFrame
        A DataFrame containing the performance metrics.
    """
    
    
    
    
    try:
               
        # Load training data
        random_sample = pd.read_csv(os.path.join(training_path, 'random_sample_of_combined_data.csv'))
        comparison_df = pd.DataFrame()

        for _, row in random_sample.iterrows():
            # Extract values from the DataFrame
            experiment, date, batch, plate, well = row['experiment'], row['date'], row['batch'], row['plate'], row['well']
            
            # Construct path to the video
            sample_path = os.path.join(training_path, 'trainingdata', experiment, f'{date}_batch{batch}_plate{plate}_well{well}')
            video_path = os.path.join(sample_path, 'raw', f'{date}_batch{batch}_plate{plate}_well{well}.mp4')
            
            # Perform image analysis with the current parameter settings
            table_of_particles = wim.image_analysis_of_sample(video_path)
            
            # Read list of true number of females in current sample
            validated_particles = pd.read_csv(os.path.join(sample_path, 'joined_particle_list', 'all_females.csv'))
                        
            # Match particles detected by image analysis to "true" particles by their position
            comparison_particles = wim.compare_detected_particles(validated_particles, table_of_particles)
            
            # Collect data across different samples
            comparison_df = pd.concat([comparison_df, comparison_particles], ignore_index=True) if not comparison_df.empty else comparison_particles
            
            print(comparison_df)
             
        # Calculate performance metrics
        performance_metrics = calculate_performance_metrics(comparison_df)
        
        # Generate screen output during run
        print("Checkpoint_1:")
        print(performance_metrics)
        
        # Read the config file
        config = read_config()
        print("Checkpoint_2:")
        print(config)
        
        particle_detection_params = config['particle_detection']
        
        print("Checkpoint_3:")
        print(particle_detection_params)
        
        performance_metrics['microorganism_threshold'] = particle_detection_params['microorganism_threshold']
        performance_metrics['min_microorganism_area'] = particle_detection_params['min_microorganism_area']
        
        
 
        return performance_metrics, comparison_df

    except Exception as e:
        logging.error(f"Error in evaluate_imaging_parameters: {e}")
        raise

def evaluate_imaging_parameters(training_path='E:/'):
    """
    Assess the effects of two imaging parameters (microorganism_threshold, min_microorganism_area) on 
    female detection performance metrics. Iterates through a curated training dataset.

    Parameters
    ----------
    microorganism_threshold: int
        Intensity threshold value of pixel (range: 0-255; default: 30)
    min_microorganism_area: int
        Contour area of detected particle (default: 150 pixels)
    training_path: str
        Main path to the dataset
    config_path: str
        Path to the configuration file

    Returns
    -------
    DataFrame
        A DataFrame containing the performance metrics.
    """
    
    
    
    
    try:
               
        # Get a list of all .mp4 video files in the directory
        video_files = [
            f for f in os.listdir(training_path) 
            if os.path.isfile(os.path.join(training_path, f)) and f.endswith('.mp4')
        ]
        
        comparison_df = pd.DataFrame()

       # Iterate through the list of video files
        for video_file in video_files:
            # Construct the full path to the video
            video_path = os.path.join(training_path, video_file)
            
            # Perform image analysis with the current parameter settings
            table_of_particles = wim.image_analysis_of_sample(video_path)
            
            # Navigate to and read the ground truth particle data
            # Remove the .mp4 extension from the video file name
            video_name = os.path.splitext(video_file)[0]     
            folder_name = f"{video_name}_particle_detection"
            
            # Construct the path to 'all_females.csv' within the folder
            csv_path = os.path.join(training_path, folder_name, 'all_females.csv')
            
            # Check if the file exists
            if not (os.path.exists(csv_path)):
                print(f"File not found: {csv_path}")
          
            validated_particles = pd.read_csv(csv_path)
                        
            # Match particles detected by image analysis to "true" particles by their position
            comparison_particles = wim.compare_detected_particles(validated_particles, table_of_particles)
            
            # Collect data across different samples
            comparison_df = pd.concat([comparison_df, comparison_particles], ignore_index=True) if not comparison_df.empty else comparison_particles
            
            #print(comparison_df)
             
        # Calculate performance metrics
        performance_metrics = calculate_performance_metrics(comparison_df)
        
       
        # Read the config file
        config = read_config()
        
        particle_detection_params = config['particle_detection']
        
        performance_metrics['microorganism_threshold'] = particle_detection_params['microorganism_threshold']
        performance_metrics['min_microorganism_area'] = particle_detection_params['min_microorganism_area']
        
        
 
        return performance_metrics, comparison_df

    except Exception as e:
        logging.error(f"Error in evaluate_imaging_parameters: {e}")
        raise
    
def batch_optimizer(config_path="wellcounter_config.yml"):
    
    """
    Optimizes imaging parameters.
    
    Reads optimization parameters from the config file and sequentially executes 
    `optimize_parameters` for different threshold values across a shared range of area values.
    
    Parameters
    ----------
    config_path : str
        Path to the configuration file.
    """
    
    # Function to append configuration to log
    def append_config_to_log():
        # Log a separator and some whitespace for readability
        logging.info("\n" + '-'*40 + "\n")
        
        # Convert the config dictionary to a YAML-formatted string
        formatted_config = yaml.dump(config, default_flow_style=False, sort_keys=False)
        
        # Log the formatted configuration
        logging.info("Configuration Settings:\n" + formatted_config)
        
        
    
    temp_file_path = backup_config()
    
    # Read the config file
    config = read_config(config_path)
    
    # Extract optimization parameters
    optimize_config = config.get('optimize', {})
    training_path = optimize_config.get('training_path', 'E:/')
    output_folder = optimize_config.get('output_folder', 'C:/')
    threshold_from = optimize_config.get('threshold_from', 4)
    threshold_to = optimize_config.get('threshold_to', 80)
    threshold_step = optimize_config.get('threshold_step', 2)
    area_from = optimize_config.get('area_from', 30)
    area_to = optimize_config.get('area_to', 400)
    area_step = optimize_config.get('area_step', 10)

    # Prepare ranges for optimization
    threshold_range = range(threshold_from, threshold_to + 1, threshold_step)
    area_range = range(area_from, area_to + 1, area_step)

    total_iterations = len(threshold_range) * len(area_range)
    iterations_completed = 0

    # Open or create the output files for writing
    outpath_csv_query = os.path.join(output_folder, f'optimize_imaging_parameters_{current_date}.csv')
    
    # Ensure the DataFrame is written to the file as it is being updated
    with open(outpath_csv_query, 'w') as outfile:
       

        for threshold in threshold_range:
            for area in area_range:
                try:
                    
                    # Load and update the config
                    config = read_config(config_path)
                    config["particle_detection"]["microorganism_threshold"] = threshold
                    config["particle_detection"]["min_microorganism_area"] = area
                    config["outputs"]["particle_detection"] = False         # Suppress particle detection outputs during optimization
                    write_config(config, config_path)
                    
                    print("Current image analysis parameters are: ")
                    print("Pixel threshold: ", threshold)
                    print("Microorganism area: ", area)
                    
                    # Evaluate parameters
                    performance_metrics_query, _ = evaluate_imaging_parameters(training_path) 
                    
                    # Determine whether to write headers: write if file does not exist or is empty
                    if not os.path.exists(outpath_csv_query) or os.path.getsize(outpath_csv_query) == 0:
                        header = True
                    else:
                        header = False
                    
                    # Open file, write data, and ensure headers are correctly managed
                    with open(outpath_csv_query, 'a', newline='') as outfile:  # 'a' mode for appending
                        performance_metrics_query.to_csv(outfile, index=False, header=header)
                    
                    iterations_completed += 1
                    progress_percentage = (iterations_completed / total_iterations) * 100
                    logging.info(f"Batch optimization progress: {progress_percentage:.2f}% completed")

                except Exception as e:
                    logging.error(f"Error in optimizing parameters at threshold {threshold} and area {area}: {e}")
                    print(f"Error in optimizing parameters at threshold {threshold} and area {area}: {e}")

    logging.info("Batch optimization completed and results saved.")    
    restore_config(temp_file_path)
    
    # Save wellcounter-configuration file to log
    append_config_to_log()   
    
if __name__ == "__main__":
    batch_optimizer(config_path="wellcounter_config.yml")
    pass

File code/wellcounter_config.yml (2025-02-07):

motion:
  analysis_duration: 3
  max_search_distance: 20
  min_trajectory_size: 5
  trajectory_random_colors: false
optimize:
  area_from: 150
  area_step: 50
  area_to: 400
  output_folder: C:/wellcounter/training_data_for_MEE
  threshold_from: 8
  threshold_step: 8
  threshold_to: 24
  training_path: C:/wellcounter/training_data_for_MEE
outputs:
  motion: true
  particle_detection: true
particle_detection:
  background_is_dark: true
  default_particle_area: 500
  filter_by_shape: false
  microorganism_blur: 5
  microorganism_threshold: 8
  min_microorganism_area: 300
  search_radius_factor: 2
  unsubtracted_threshold: 70
system:
  image_height_px: 4504
  image_width_px: 4504
wellplate:
  auto_center_mask: false
  create_mask: false
  perfect_circle: true
  radius_px: 2200
  type: 6

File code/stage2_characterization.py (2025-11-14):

"""Utilities for Stage 02 particle characterization outputs.

This module augments the Stage 02 workflow with a final step that selects the
particle whose ``main_area_filled`` value lies at the median of the
``final_particles`` table. The selected particle is exported as:

1. A cropped image focused on its bounding box.
2. A CSV file containing all attributes of the median particle.

Both artifacts are written to ``stage2_characterization/final_median``.

The helper functions intentionally avoid assumptions about how Stage 02 stores
its intermediate files. They look for sensible defaults (for example,
``stage2_characterization/final_particles/final_particles.csv``) but also allow
paths to be provided explicitly.  Bounding boxes can be stored either as
``bounding_x``, ``bounding_y``, ``bounding_w`` and ``bounding_h`` columns (as
produced by :func:`wellcounter_imaging_module.calculate_measurements`) or as
``min/max`` coordinate pairs (``xmin``, ``ymin``, ``xmax``, ``ymax`` and common
variations).  Likewise, the source image can be specified in the particle row
via ``image_path``/``frame_path``/``source_image`` columns or provided as a
function argument.

Example
-------
Run the module as a script once Stage 02 produced ``final_particles``::

    python code/stage2_characterization.py \
        --stage2-root /data/stage2_characterization \
        --final-particles final_particles/final_particles.csv \
        --reference-image reference_images/frame1_particles.jpg

Relative paths for ``--final-particles`` and ``--reference-image`` are resolved
from ``--stage2-root`` so that all inputs remain inside the
``stage2_characterization`` folder. When ``--stage2-root`` is omitted the script
attempts to infer it from the current working directory or the provided
``--final-particles`` path.  The command writes the cropped median particle
image and metadata CSV into ``stage2_characterization/final_median``.
"""

from __future__ import annotations

import argparse
import re
from pathlib import Path
from typing import Iterable, Optional, Sequence, Tuple

import cv2
import pandas as pd

IMAGE_EXTENSIONS: Sequence[str] = (".png", ".jpg", ".jpeg", ".tif", ".tiff", ".bmp")
FINAL_MEDIAN_SUBDIR = "final_median"
DEFAULT_STAGE2_ROOT = Path("stage2_characterization")


def stage2_save_median_particle(
    stage2_root: str | Path = DEFAULT_STAGE2_ROOT,
    final_particles_path: Optional[str | Path] = None,
    reference_image_path: Optional[str | Path] = None,
    area_column: str = "main_area_filled",
    padding: int = 10,
) -> Tuple[Path, Path]:
    """Export the median particle artifacts for Stage 02.

    Parameters
    ----------
    stage2_root:
        Folder that contains Stage 02 outputs (``stage2_characterization`` by
        default). When omitted or when the default path does not exist, the
        function attempts to infer the correct directory from the supplied
        ``final_particles_path`` or the current working directory.
    final_particles_path:
        Optional path (absolute or relative to ``stage2_root``) that points to
        the CSV file with the ``final_particles`` table. When omitted, the
        function searches for a file named ``final_particles*.csv`` under
        ``stage2_root``.
    reference_image_path:
        Path to the image that contains the bounding boxes referenced by
        ``final_particles``.  Relative paths are interpreted with respect to
        ``stage2_root`` to keep all inputs inside the Stage 02 directory. When
        omitted, the function attempts to infer the image path from the
        particle table or by scanning the Stage 02 folder.
    area_column:
        Name of the column that stores the ``main_area_filled`` measurement.
    padding:
        Extra pixels added to every side of the bounding box when cropping.

    Returns
    -------
    tuple(Path, Path)
        Paths to the cropped image and CSV metadata that were written.
    """

    stage2_root = _normalize_stage2_root(stage2_root, final_particles_path)
    final_particles_file = _locate_final_particles_file(stage2_root, final_particles_path)
    particles_df = _load_particles(final_particles_file)

    median_row, median_value = _select_median_row(particles_df, area_column)
    bbox = _resolve_bounding_box(median_row)
    reference_image = _resolve_reference_image(
        median_row, stage2_root, reference_image_path, final_particles_file.parent
    )
    cropped_image = _crop_particle_image(reference_image, bbox, padding)

    output_dir = stage2_root / FINAL_MEDIAN_SUBDIR
    output_dir.mkdir(parents=True, exist_ok=True)

    base_name = _determine_output_basename(median_row, final_particles_file)
    image_output_path = output_dir / f"{base_name}_median_particle.png"
    csv_output_path = output_dir / f"{base_name}_median_particle.csv"

    if not cv2.imwrite(str(image_output_path), cropped_image):
        raise RuntimeError(f"Failed to save cropped image to {image_output_path}")

    metadata_df = median_row.to_frame().T.copy()
    metadata_df["median_main_area_filled"] = median_value
    metadata_df["median_particle_image"] = image_output_path.name
    metadata_df.to_csv(csv_output_path, index=False)

    print(
        "Median particle artifacts saved to",
        f"{image_output_path} and {csv_output_path}",
    )
    return image_output_path, csv_output_path


def _normalize_stage2_root(stage2_root: str | Path, final_particles_path: Optional[str | Path]) -> Path:
    """Resolve the Stage 02 root directory with a few useful fallbacks."""

    candidate = Path(stage2_root)
    if candidate.exists():
        return candidate.resolve()

    # Allow callers to pass a final_particles file outside the default root. If
    # an explicit path is provided and exists, the root can be inferred from it.
    cwd = Path.cwd().resolve()
    if final_particles_path:
        explicit = Path(final_particles_path)
        if explicit.is_absolute() and explicit.exists():
            return explicit.parent.resolve()
        relative_candidate = (cwd / explicit).resolve()
        if relative_candidate.exists():
            return relative_candidate.parent

    # When no explicit root exists, look for a nearby folder that resembles the
    # Stage 02 layout (e.g., current directory or a child directory that matches
    # the default name).
    fallbacks: Iterable[Path] = (
        cwd,
        cwd / DEFAULT_STAGE2_ROOT,
    )

    for fallback in fallbacks:
        if not fallback.exists():
            continue
        if list(fallback.glob("final_particles*.csv")):
            return fallback
        nested = fallback / "final_particles"
        if nested.exists() and list(nested.glob("final_particles*.csv")):
            return fallback

    raise FileNotFoundError(
        "Unable to resolve the Stage 02 root directory. Pass --stage2-root or "
        "ensure that the default 'stage2_characterization' folder exists."
    )
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

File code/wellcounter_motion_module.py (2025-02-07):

# -*- coding: utf-8 -*-
"""
Wellcounter motion module

This software is part of the following publication:
"Wellcounter: Automated High-Throughput Phenotyping for Aquatic Microinvertebrates"
Methods in Ecology and Evolution

The latest version can be found at https://github.com/cpstelzer/wellcounter


Description:
This module contains several low-level and high-level functions for analyzing the
swimming behavior of microorganisms recorded in the WELLCOUNTER. Particle 
identification is done with the wellcounter_imaging_module.

Note: Portions of the code in this file were generated using ChatGPT v4.0.
      All AI-generated content has been rigorously validated and tested by the 
      authors. The corresponding author accepts full responsibility for the 
      AI-assisted portions of the code.

Author: Claus-Peter Stelzer
Date: 2025-02-07

"""

import cv2
import wellcounter_imaging_module as wim
import pandas as pd
import numpy as np
import random
import os
import yaml


# Load global config
config_path = "wellcounter_config.yml"
with open(config_path, 'r') as file:
    config = yaml.safe_load(file)
    
    
def record_particle_positions_in_video(video_path):
    
    """
    Records the positions of particles in a video and generates a long exposure image.

    This function processes a video file to detect and record the positions of particles in each frame, 
    within a specified analysis duration. It also generates a long exposure image showing the cumulative paths 
    of these particles.

    The function operates as follows:
    - Opens the video file and determines the frame rate.
    - Calculates the number of frames to process based on the analysis duration and frame rate.
    - Iterates over the specified number of frames, performing the following steps for each frame:
        - Extracts a frame from the video with a specific delay.
        - Performs image subtraction and particle analysis on the extracted frame using specified particle_detection parameters.
        - Records the positions and other attributes of particles detected in the frame.
        - Updates the long exposure image with the trajectory of particles in the current frame.
    - The process results in a DataFrame containing particle information for each processed frame and a long exposure image.

    Args:
        video_path (str): Path to the video file for analysis.
        analysis_duration (float): Duration (in seconds) of the video to be analyzed.
        particle_detection_params (dict): Parameters for particle detection and particle_detection processing.

    Returns:
        tuple: A tuple containing two elements:
               - A DataFrame with recorded particle positions and other attributes for each processed frame.
               - A long exposure image showing the cumulative paths of particles across the processed frames.
    """
    
    motion_params = config['motion']  
    
    # Read frame rate
    cap = cv2.VideoCapture(video_path)
    if not cap.isOpened():
        print("Error: Could not open video file")
        exit()
    frame_rate = int(cap.get(cv2.CAP_PROP_FPS))
    cap.release()

    first_frame = wim.extract_frame(video_path, delay=0)
    height, width = first_frame.shape
    step = 1 / frame_rate
    number_of_iterations = int(motion_params['analysis_duration'] * frame_rate)
    long_exposure_image = np.zeros((height, width), dtype=np.uint8)
    result_df = pd.DataFrame()

    for i in range(number_of_iterations):
        print(f"Motion analysis\nProcessing frame no. {i} of {number_of_iterations}")
        secsA = i * step
        secsB = secsA + 5
        subtr_image, masked_image = wim.image_subtraction_from_video(video_path, delay1=secsA, delay2=secsB)
        table_of_particles, binary_image = wim.analyze_microorganisms(subtr_image)
        table_of_particles.insert(0, 'frame', i + 1)
        result_df = pd.concat([result_df, table_of_particles], ignore_index=True)
        long_exposure_image = cv2.add(long_exposure_image, binary_image)
        long_exposure_image = np.clip(long_exposure_image, 0, 255).astype(np.uint8)
    
    return result_df, long_exposure_image


def track_particles(particles_by_frame):
    
    """
    Tracks particles across frames and assigns them to trajectories based on proximity.

    This function iterates through particles sorted by frame number and assigns each particle 
    to the closest existing trajectory. A new trajectory is created if no existing trajectory 
    is close enough. The function calculates the Euclidean distance between particles and the 
    last point in each trajectory to determine closeness. Trajectories that are shorter than 
    a predefined minimum size are removed at the end.

    Args:
        particles_by_frame (DataFrame): A DataFrame containing particle information for each frame. 
                                        Each row should have at least 'frame', 'X', 'Y', and 'area' columns.
        motion_params (dict): A dictionary containing parameters for motion analysis. 
                              Should include 'max_search_distance' (the maximum distance to search for an 
                              existing trajectory) and 'min_trajectory_size' (the minimum acceptable size 
                              for a trajectory).

    Returns:
        dict: A dictionary of trajectories where each key is a trajectory ID and the value is a list of tuples.
              Each tuple represents a particle's frame number, X and Y coordinates, and other attributes (e.g., area).
              The trajectories are filtered to remove those shorter than the minimum size threshold.
    """
    
    motion_params = config['motion'] 
    
    # Initialize an empty dictionary to store the trajectories.
    trajectories = {}

    # Sort the input DataFrame by frame number for chronological processing.
    input_data = particles_by_frame.sort_values(by='frame')

    # Iterate through each row (particle) in the sorted DataFrame.
    for _, row in input_data.iterrows():
        # Extract frame number, x and y coordinates, and area from the current row.
        frame, x, y, area = row['frame'], row['X'], row['Y'], row['area']

        # Initialize variables to track the closest trajectory and its distance.
        closest_id = None
        min_distance = float('inf')

        # Iterate through each existing trajectory to find the closest one.
        for obj_id, trajectory in trajectories.items():
            # Get the last point (frame, x, y, area) of the current trajectory.
            last_frame, last_x, last_y, last_area = trajectory[-1]

            # Calculate the Euclidean distance between the current particle and the last point of this trajectory.
            distance = ((x - last_x) ** 2 + (y - last_y) ** 2) ** 0.5
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

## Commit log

2024-07-16 .gitattributes, .gitignore und LICENSE.txt hinzufügen.
2025-11-14 Add stage 2 median particle export step
2025-11-14 Document Stage 02 reference path handling
2025-11-14 Improve Stage 02 median export discovery
